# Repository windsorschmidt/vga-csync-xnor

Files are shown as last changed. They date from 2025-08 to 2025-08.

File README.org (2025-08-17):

* About

Combines VGA horizontal and vertical synchronization signals into 75Ω
composite sync for use with analog CRT displays such as PVMs/BVM's, or
televisions with RGBS inputs, e.g. SCART or RGB-modified televisions.

[[vga-csync-xnor.png?raw=true]]

* EDID EEPROM

An on-board EEPROM allows the adapter to store and serve an EDID to
the host PC to automatically configure a TV-compatible video mode.

In Linux, [[https://github.com/ChalkElec/write-edid][write-edid]] may be used to program the EEPROM with an
EDID. Sample EDID files have been included.

* License

Circuit schematic and PCB layout are licensed under CERN-OHL-S v2.

See [[LICENSE.txt]].

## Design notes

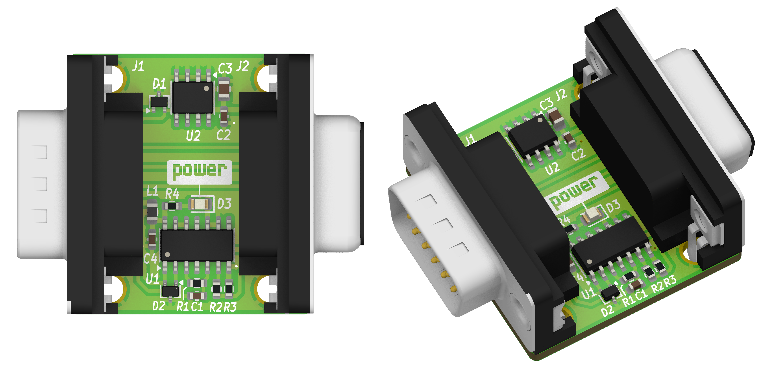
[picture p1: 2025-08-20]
vga-csync-xnor.png

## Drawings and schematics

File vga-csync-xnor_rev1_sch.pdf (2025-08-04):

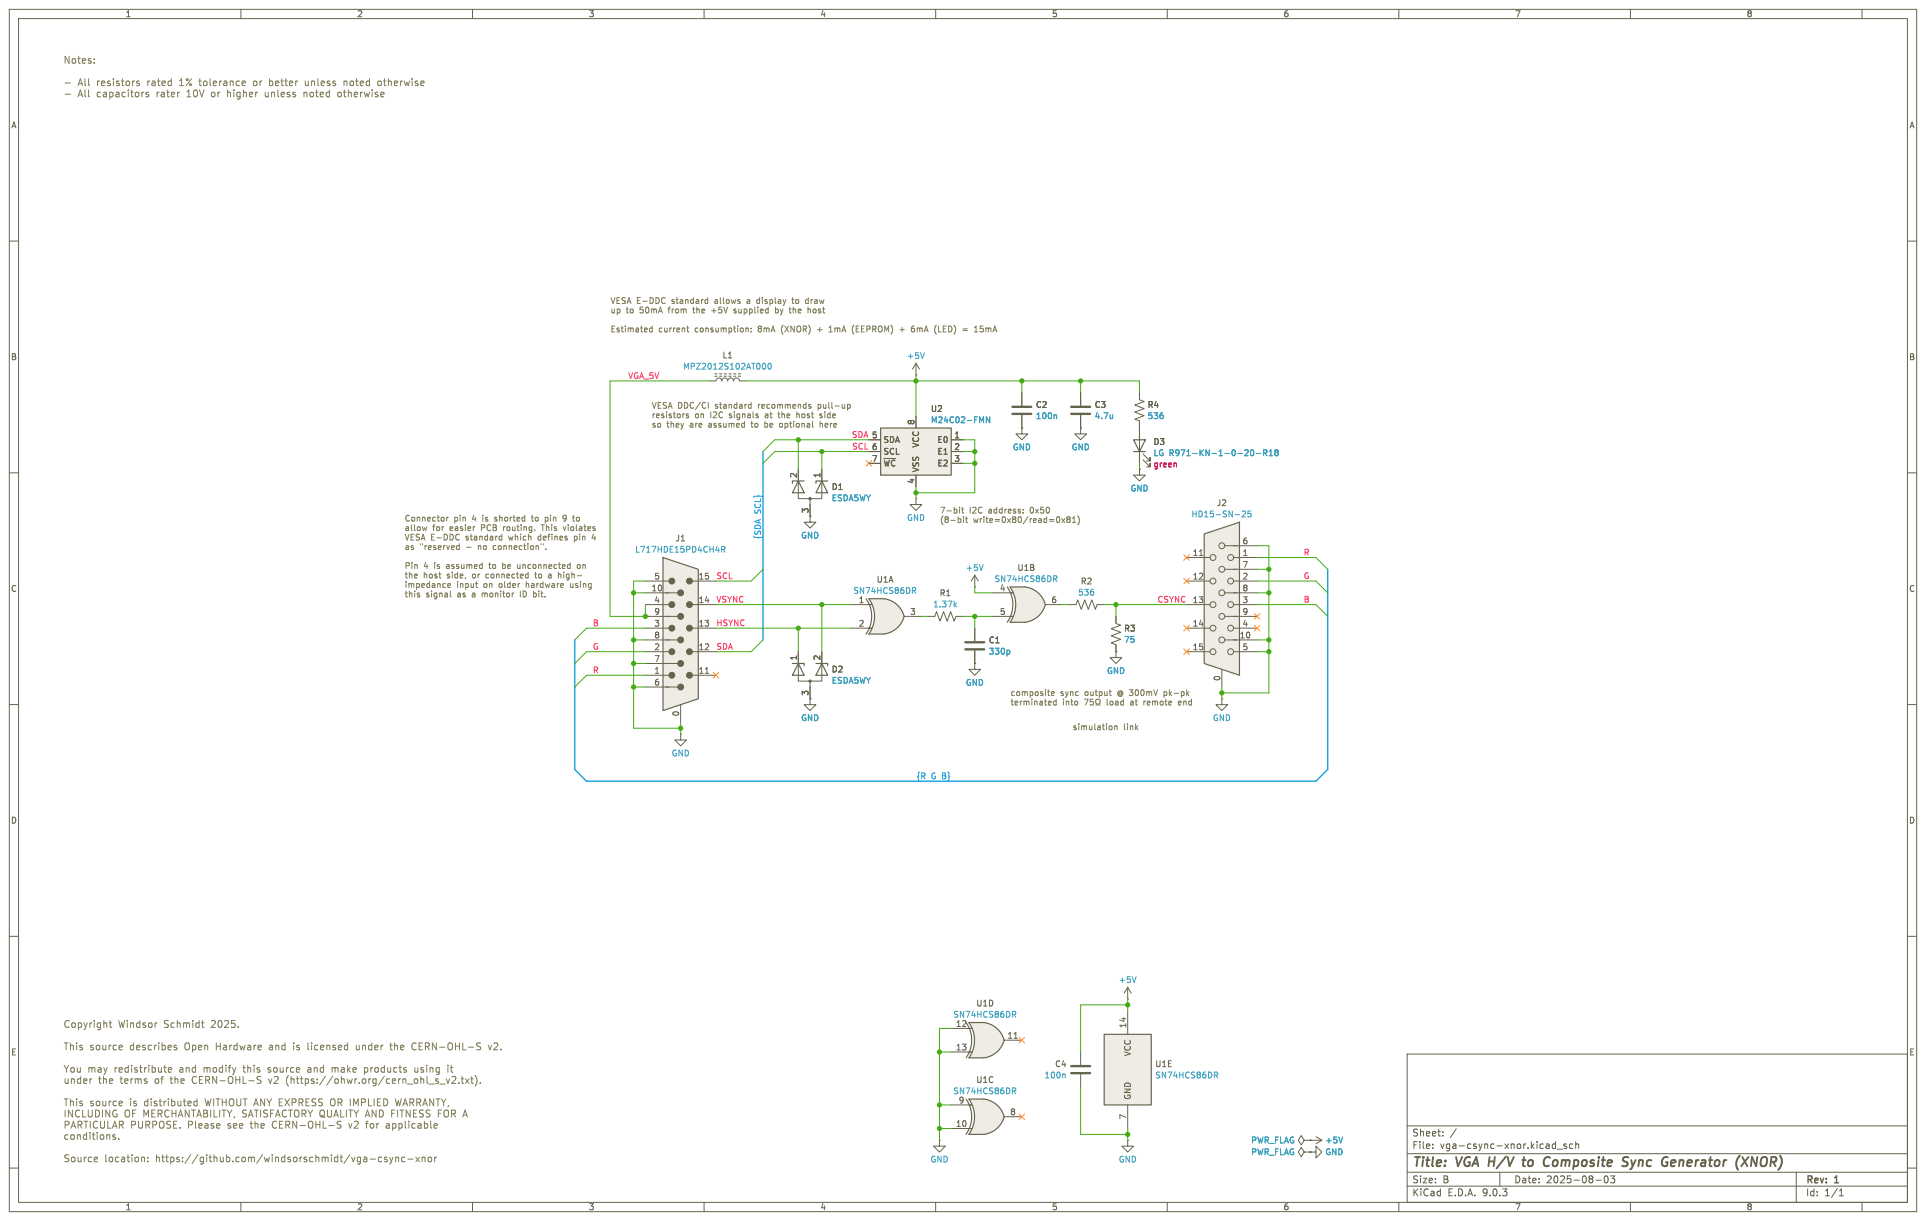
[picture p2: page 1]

4 SDA 5 SCL 6 ~{WC} 7 U2 M24C02-FMN GND GND

INCLUDING OF MERCHANTABILITY, SATISFACTORY QUALITY AND FITNESS FOR A

Id: 1/1 Title: VGA H/V to Composite Sync Generator (XNOR) File: vga-csync-xnor.kicad_sch Sheet: /

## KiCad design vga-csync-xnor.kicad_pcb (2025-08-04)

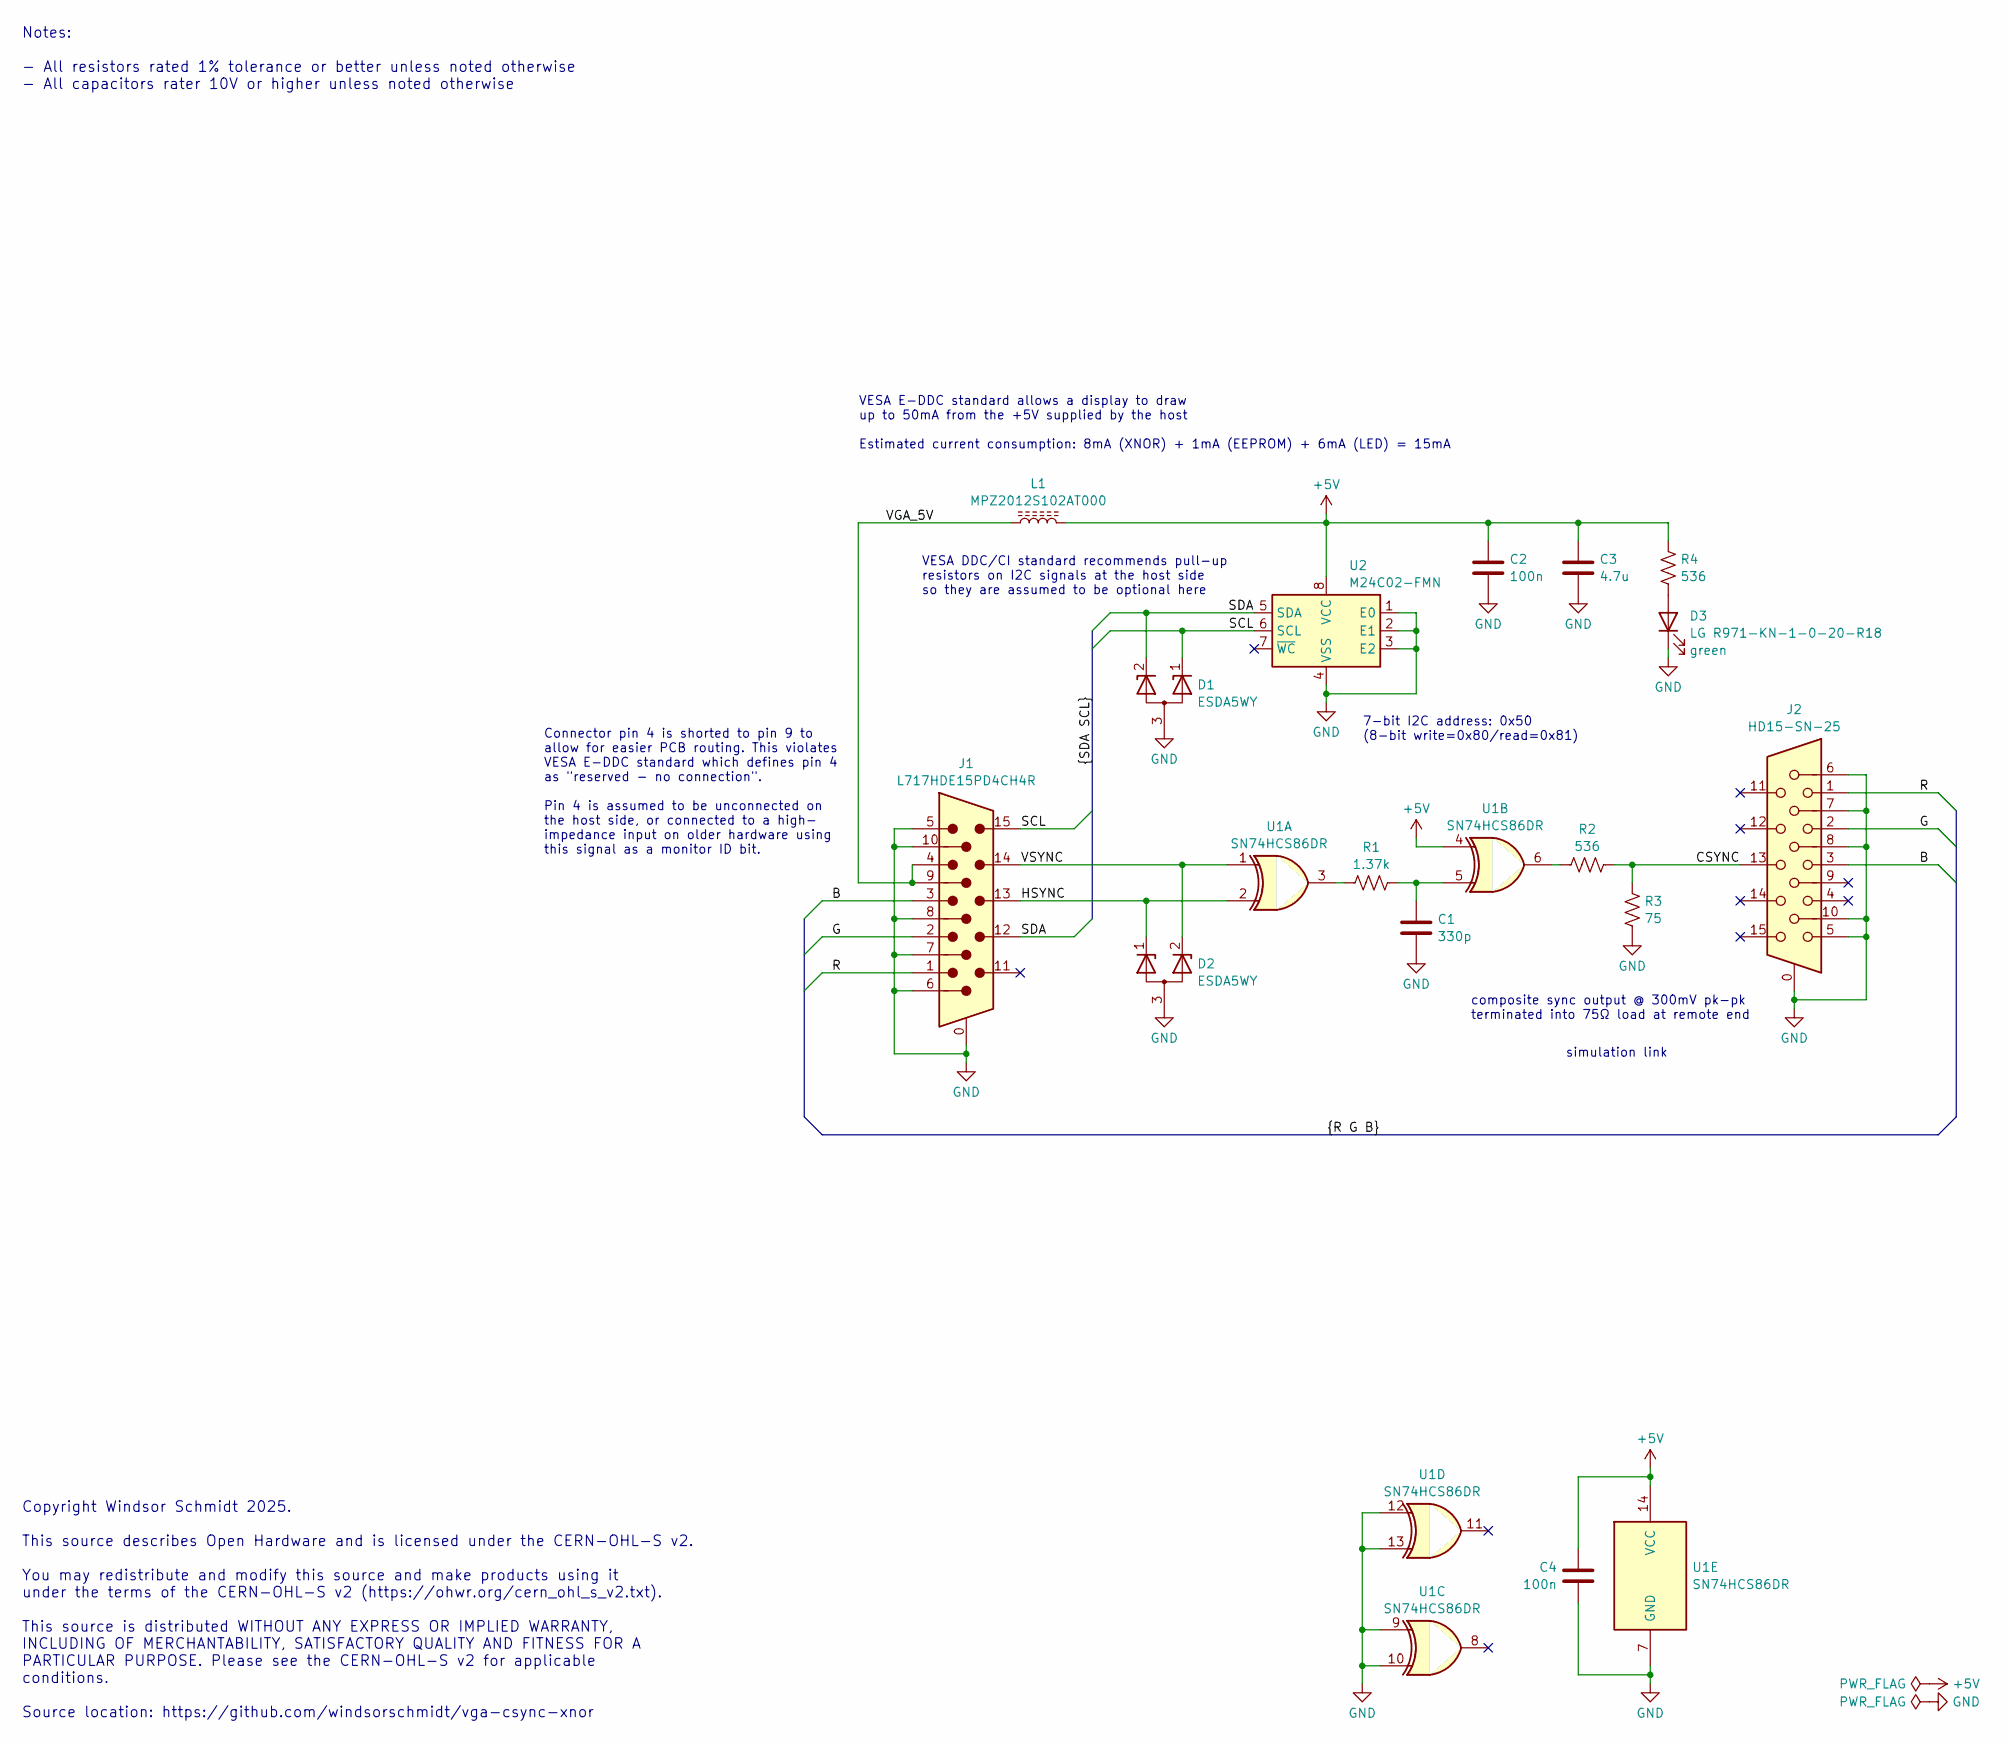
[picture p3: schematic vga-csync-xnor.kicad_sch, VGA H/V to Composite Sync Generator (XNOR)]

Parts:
C1: 330p; C_0603_1608Metric
C2, C4: 100n; C_0603_1608Metric
C3: 4.7u; C_0805_2012Metric
D1, D2: ESDA5WY; SOT-323_SC-70
D3: LG R971-KN-1-0-20-R18; LED_0805_2012Metric
J1: L717HDE15PD4CH4R; DSUB-15-HD_Pins_Horizontal_P2.29x1.90mm_EdgePinOffset3.03mm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
J2: HD15-SN-25; DSUB-15-HD_Socket_Horizontal_P2.29x1.90mm_EdgePinOffset3.03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
L1: MPZ2012S102AT000; L_0805_2012Metric
R1: 1.37k; R_0603_1608Metric
R2, R4: 536; R_0603_1608Metric
R3: 75; R_0603_1608Metric
U1: SN74HCS86DR; SOIC-14_3.9x8.7mm_P1.27mm
U2: M24C02-FMN; SOIC-8_3.9x4.9mm_P1.27mm

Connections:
+5V: C2.1, C3.1, C4.1, L1.2, R4.2, U1.4, U1.14 (VCC), U2.8 (VCC)
/B: J1.3, J2.3
/CSYNC: J2.13, R2.1, R3.1
/G: J1.2, J2.2
/HSYNC: D2.1 (K), J1.13, U1.2
/R: J1.1, J2.1
/SCL: D1.1 (K), J1.15, U2.6 (SCL)
/SDA: D1.2 (K), J1.12, U2.5 (SDA)
/VGA_5V: J1.4, J1.9, L1.1
/VSYNC: D2.2 (K), J1.14, U1.1
GND: C1.2, C2.2, C3.2, C4.2, D1.3 (A), D2.3 (A), D3.1 (K), J1.0, J1.5, J1.6, J1.7, J1.8, J1.10, J2.0, J2.5, J2.6, J2.7, J2.8, J2.10, R3.2, U1.7 (GND), U1.9, U1.10, U1.12, U1.13, U2.1 (E0), U2.2 (E1), U2.3 (E2), U2.4 (VSS)
unnamed: C1.1, R1.2, U1.5
unnamed: D3.2 (A), R4.1
unnamed: R1.1, U1.3
unnamed: R2.2, U1.6

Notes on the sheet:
7-bit I2C address: 0x50 (8-bit write=0x80/read=0x81)
simulation link
Notes: - All resistors rated 1% tolerance or better unless noted otherwise - All capacitors rater 10V or higher unless noted otherwise
composite sync output @ 300mV pk-pk terminated into 75Ω load at remote end
Copyright Windsor Schmidt 2025. This source describes Open Hardware and is licensed under the CERN-OHL-S v2. You may redistribute and modify this source and make products using it under the terms of the CERN-OHL-S v2 (https://ohwr.org/cern_ohl_s_v2.txt). This source is distributed WITHOUT ANY EXPRE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
VESA E-DDC standard allows a display to draw up to 50mA from the +5V supplied by the host Estimated current consumption: 8mA (XNOR) + 1mA (EEPROM) + 6mA (LED) = 15mA
VESA DDC/CI standard recommends pull-up resistors on I2C signals at the host side so they are assumed to be optional here
Connector pin 4 is shorted to pin 9 to allow for easier PCB routing. This violates VESA E-DDC standard which defines pin 4 as "reserved - no connection". Pin 4 is assumed to be unconnected on the host side, or connected to a high- impedance input on older hardware using this signal as a monitor ID 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

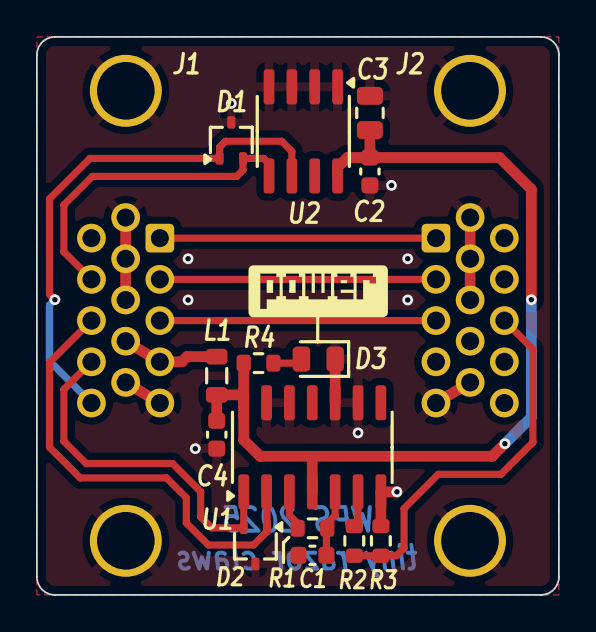
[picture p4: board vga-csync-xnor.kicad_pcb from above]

Board: 2 copper layers, 29.0 x 31.0 mm, 16 parts (0 on the bottom side), 15 nets.
